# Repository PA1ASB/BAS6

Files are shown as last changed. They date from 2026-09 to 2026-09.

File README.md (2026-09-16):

# BAS6 - Remote controlled receive antenna switch for 6 beverage antennas

This project describes a 6-way receive antenna switch I built for a fellow radio amateur that allows to select one of six beverage wire antennas remotely and producing as little as possible noise around the connection to his receive amplifier. Using bi-stable relays makes it possible to completely disconnect power to the relays once an antenna has been selected. Switching is controlled by a small circuit, built in a tiny aluminium extrusion desktop enclosure, using two UP/DOWN tactile switches. Bi-colour LED’s on the from panel indicate the currently connected antenna and, when using the selection buttons, the next antenna to be switched on. Connection between the control station in the shack and the actual relay box requires 4 wires; using cheap UTP/FTP is therefore possible. The circuit should work over distances in excess of 200 meters as communication between the stations is done through two current loops (receive and transmit).

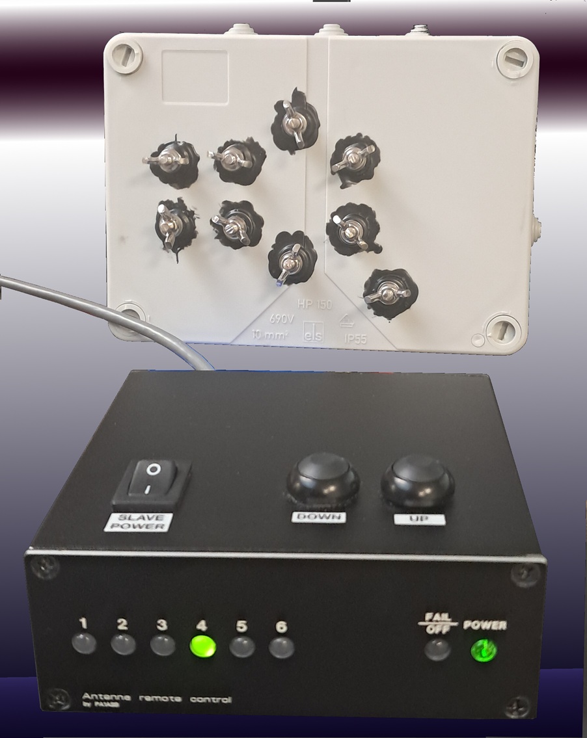
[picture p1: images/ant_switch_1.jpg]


Control unit and relay box communicate “digitally” by sending some pulses to and fro, the number of which determine what the relaybox should actually do. After executing a command, the circuit measures which relay is actually switched on / off and reports this back to the control unit again as a series of pulses. If for whatever reason the reported switch state differs from what has been commanded, an error is indicated so that  the user knows there’s something wrong. This will prevent unnecessary walks from the shack to the antenna connections: what is  indicated on the control unit is the actual state.

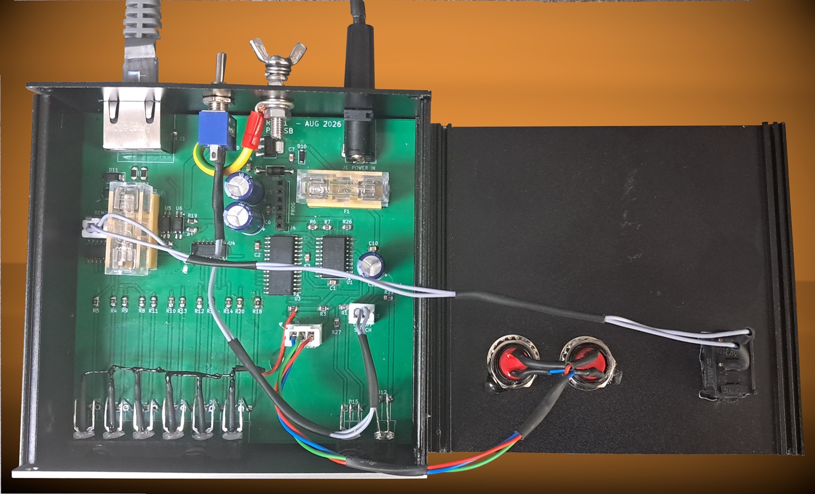
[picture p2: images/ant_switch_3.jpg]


The antennas are connected to the switch on the PVC junction box. I have made quite some effort in making the box and connections that are located outside of the box as watertight as possible but I guess that it is still advisable to make some additional protection to prevent direct exposure to the environment.

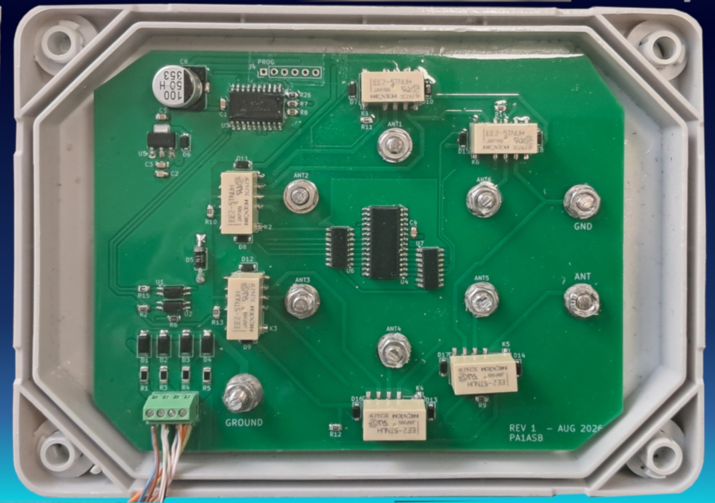
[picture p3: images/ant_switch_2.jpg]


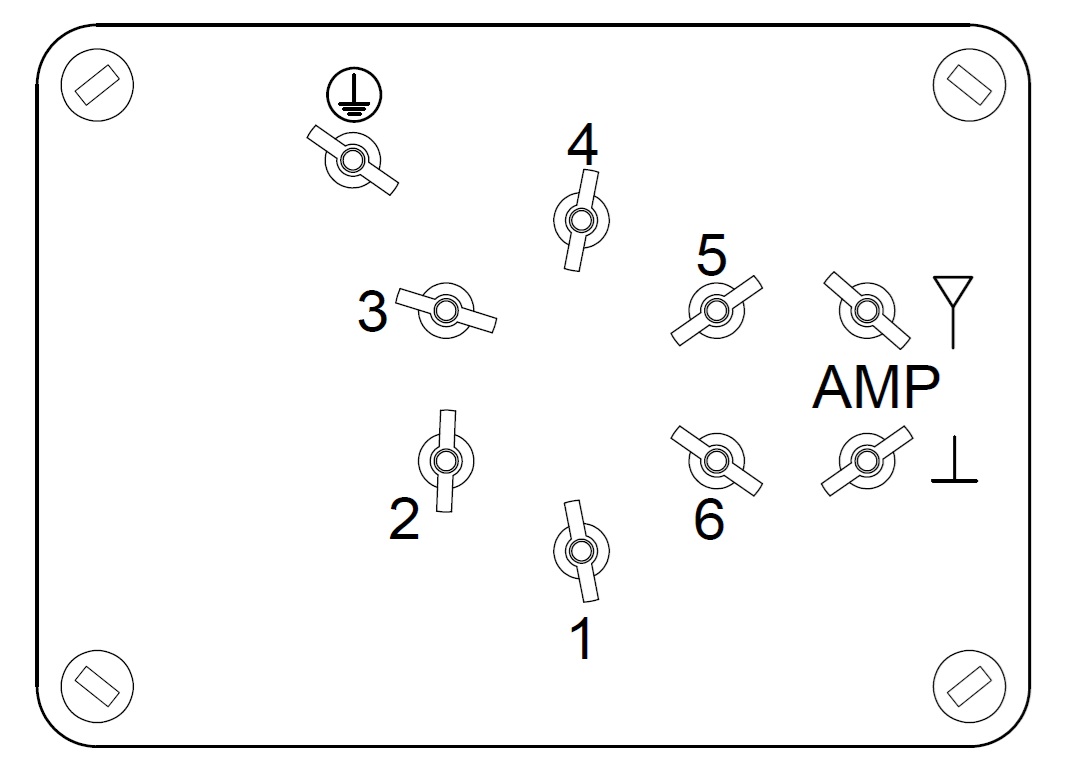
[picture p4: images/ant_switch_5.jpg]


You can find the schematics of both units both as PDF and KiCAD v10 files as well as the C sources. I have also included BOM files for the PCB’s. There’s some additional hardware required such as stainless steel hardware for the antenna connections and switches to control the relays; these are not mentioned in these files. I have built the software in MPLAB IDE with the XC8 1.33 compiler. The C source should also compile in the newer MPLAB X IDE with the newer compiler versions but I believe that there are some minor syntax changes between the old and new versions which obviously need to be resolved. Google will be your friend for that, I guess.

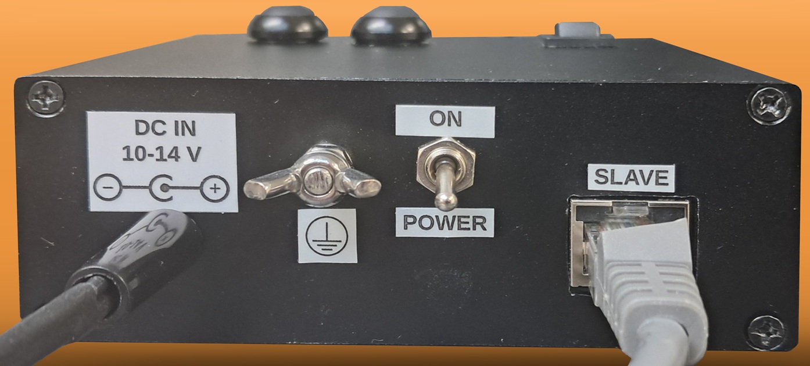
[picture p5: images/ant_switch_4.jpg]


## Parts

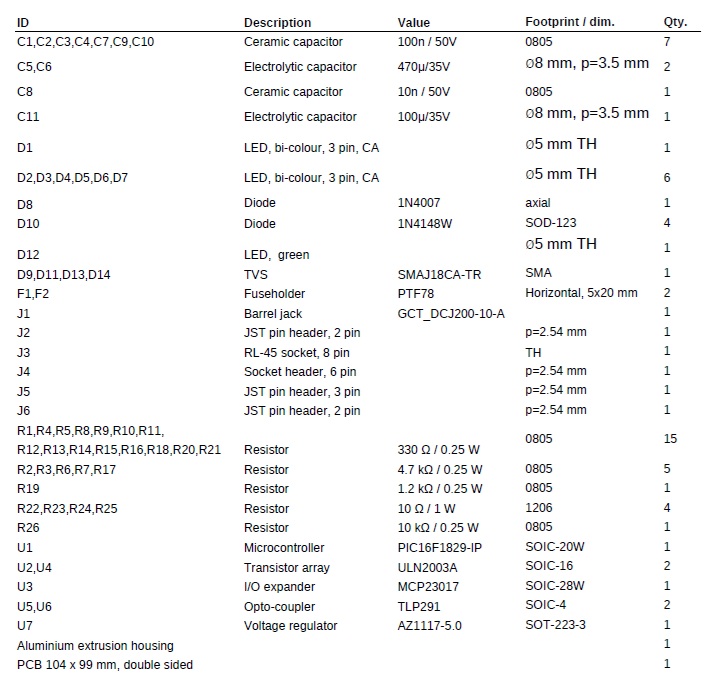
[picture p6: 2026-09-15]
hardware/controller/BOM.jpg

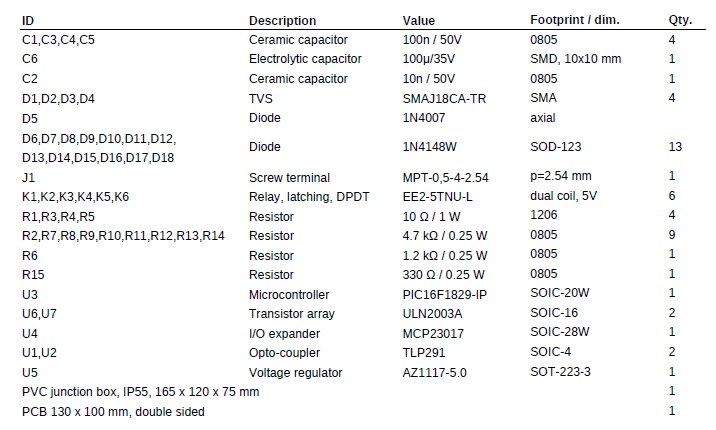
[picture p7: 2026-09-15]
hardware/switch/BOM.jpg

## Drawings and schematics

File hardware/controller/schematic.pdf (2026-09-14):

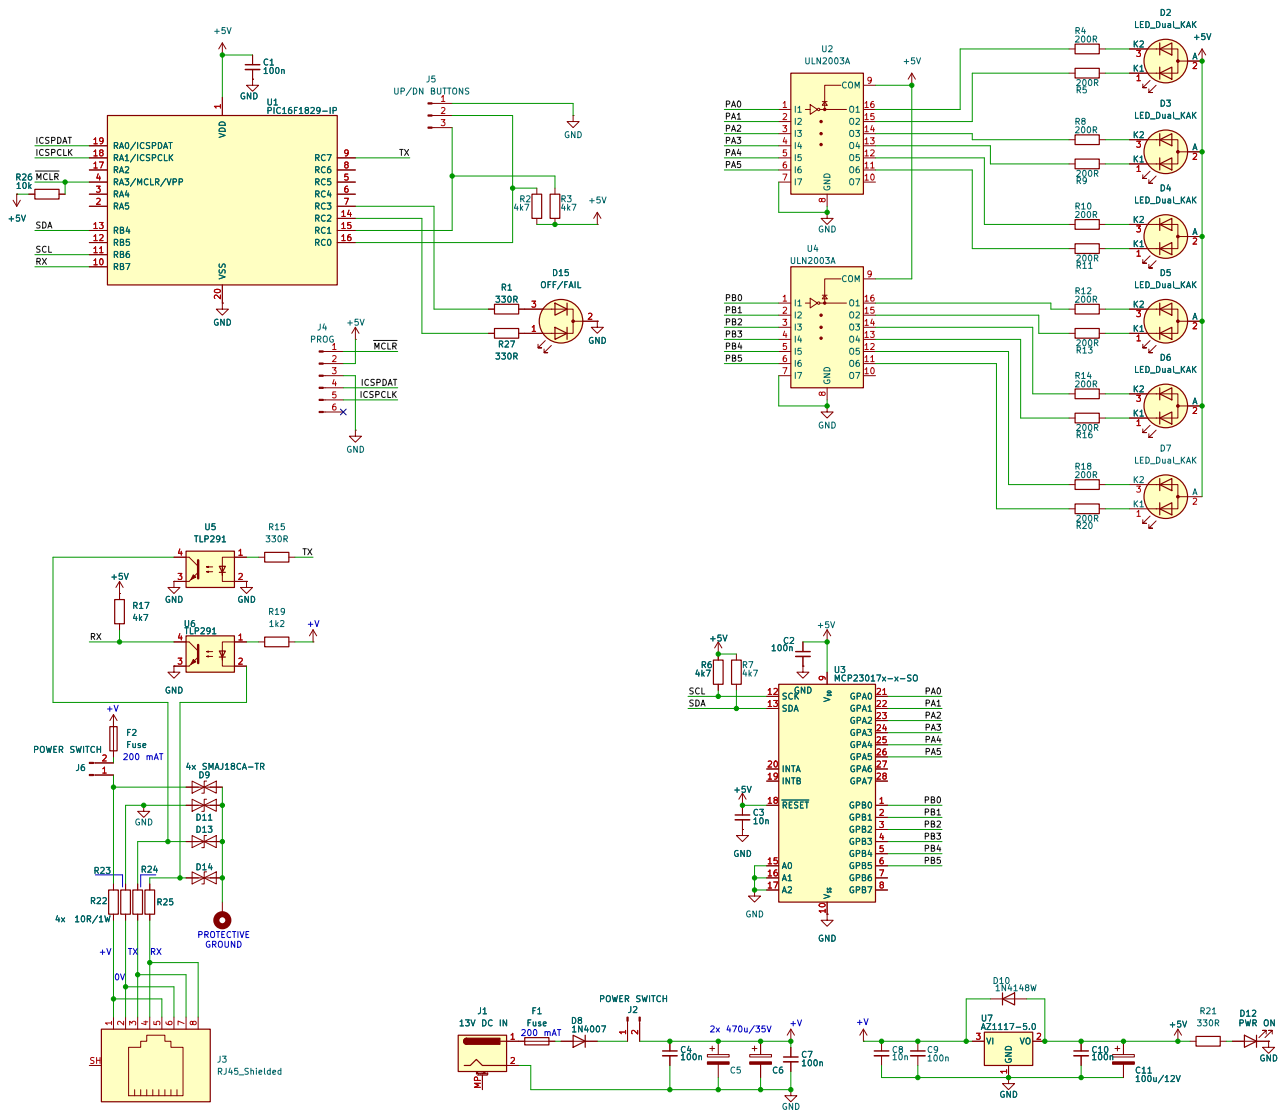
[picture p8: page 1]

1 RA5 2 RA4 3 RA3/MCLR/VPP 4 RC5 5 RC4 6 RC3 7 RC6 8 RC7 9 RB7 10 RB6 11 RB5 12 RB4 13 RC2 14 RC1 15 RC0 16 RA2 17 RA1/ICSPCLK 18 RA0/ICSPDAT 19 VSS 20 U1PIC16F1829-IP

1 RA5 2 RA4 3 RA3/MCLR/VPP 4 RC5 5 RC4 6 RC3 7 RC6 8 RC7 9 RB7 10 RB6 11 RB5 12 RB4 13 RC2 14 RC1 15 RC0 16 RA2 17 RA1/ICSPCLK 18 RA0/ICSPDAT 19 VSS 20 GND +5VR26

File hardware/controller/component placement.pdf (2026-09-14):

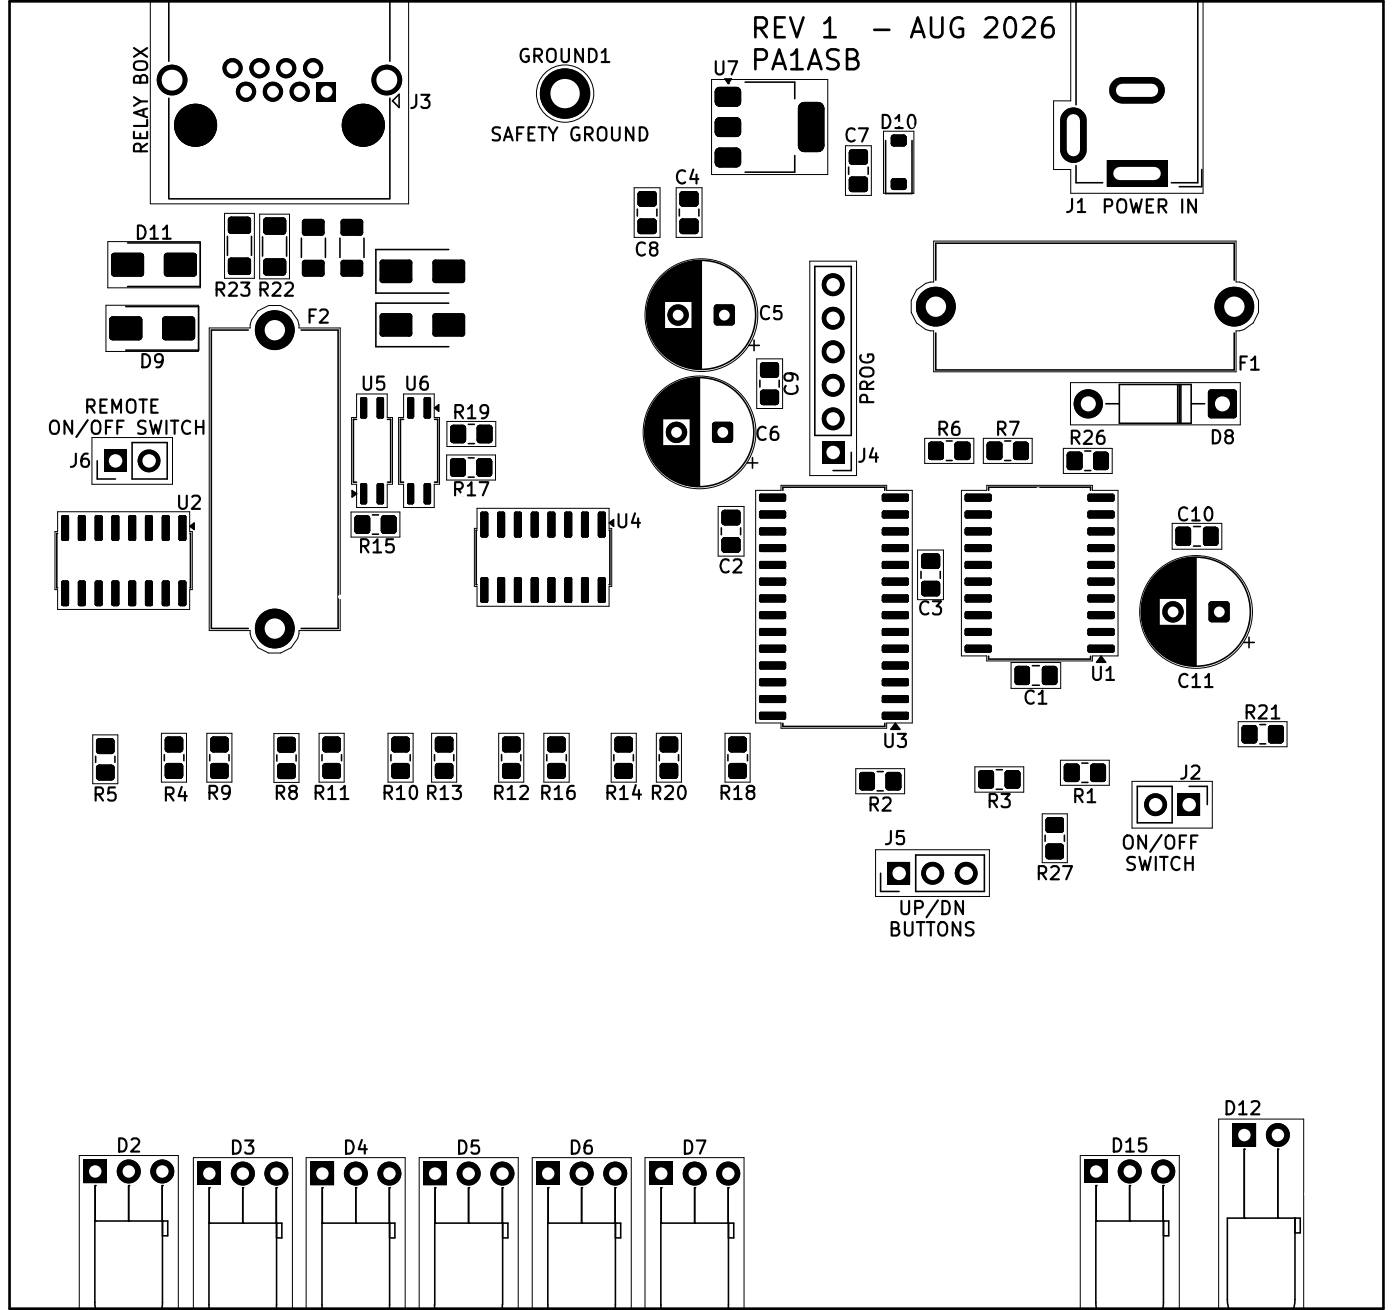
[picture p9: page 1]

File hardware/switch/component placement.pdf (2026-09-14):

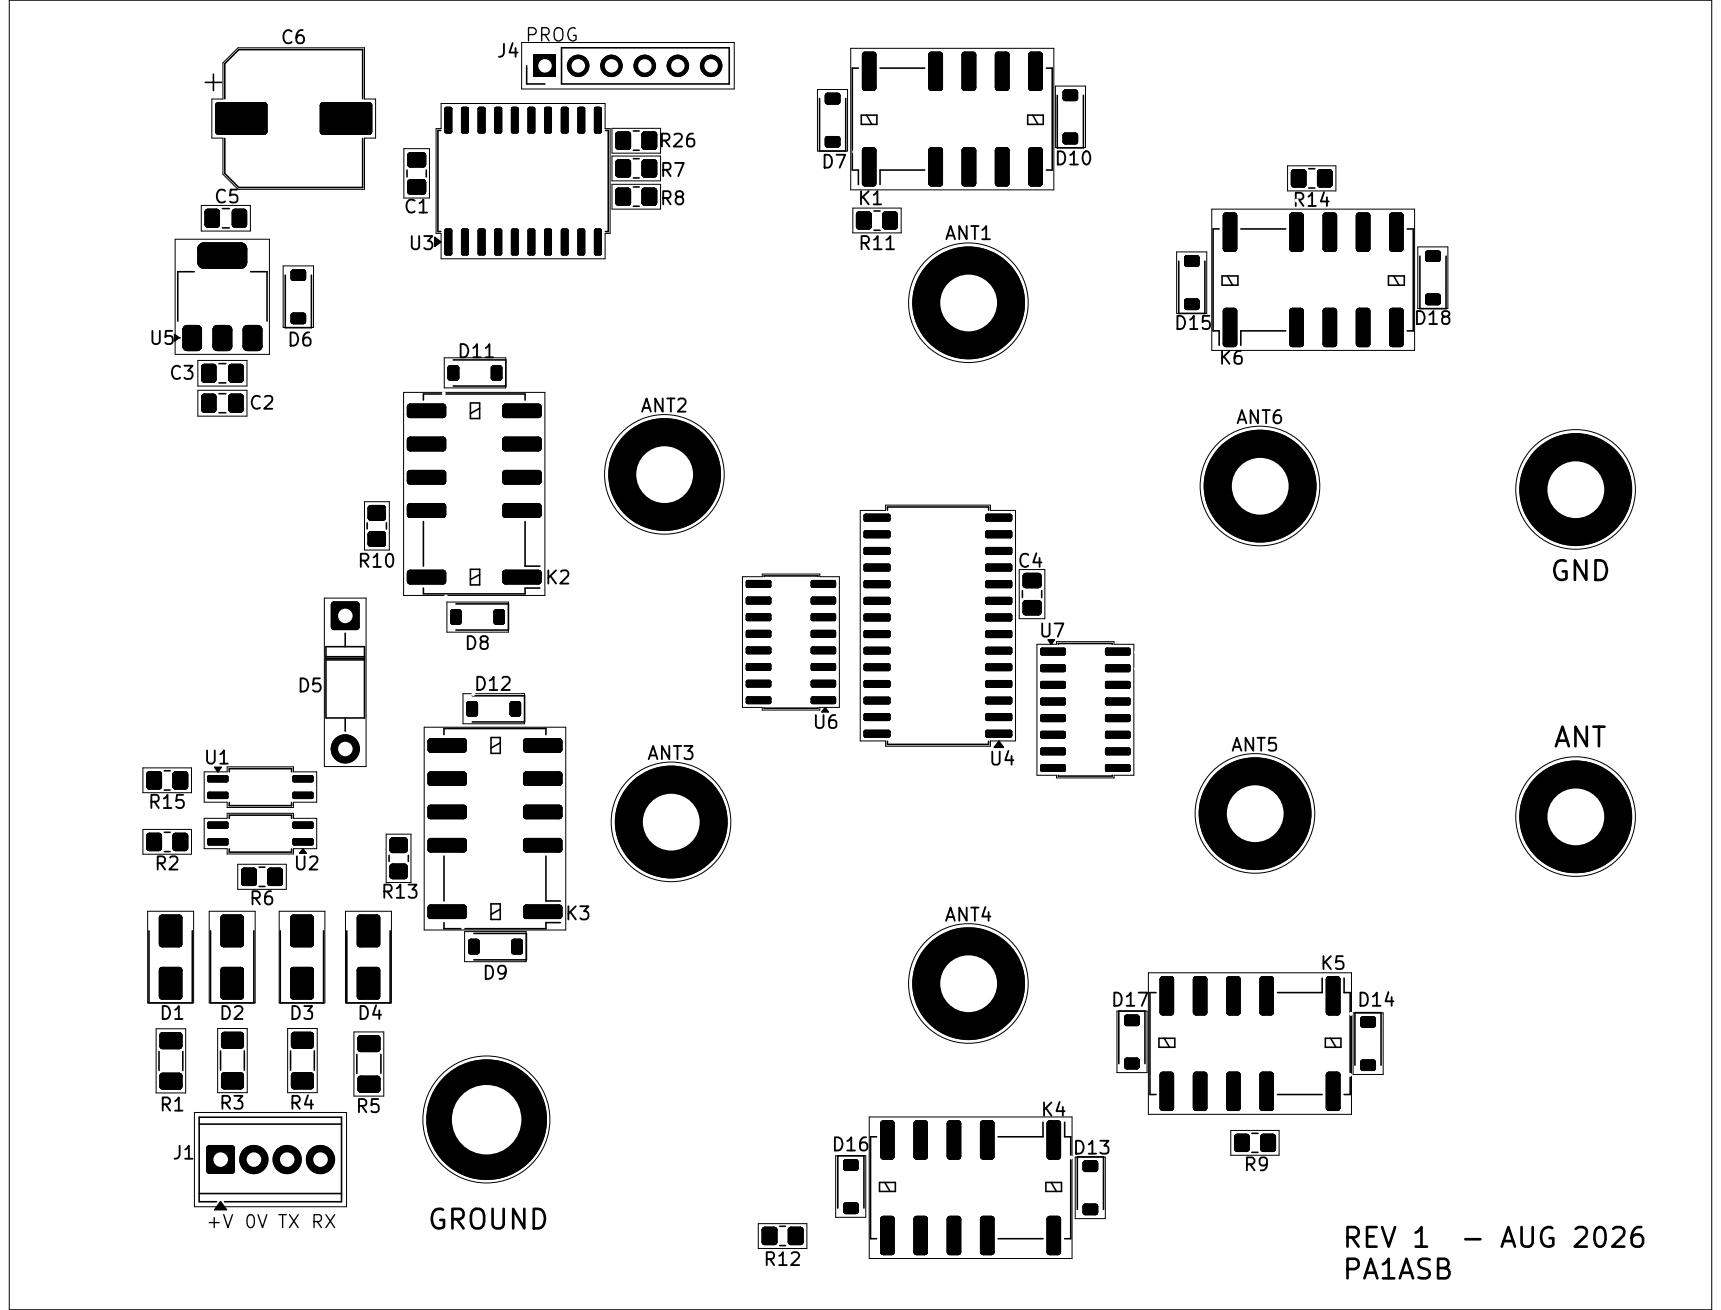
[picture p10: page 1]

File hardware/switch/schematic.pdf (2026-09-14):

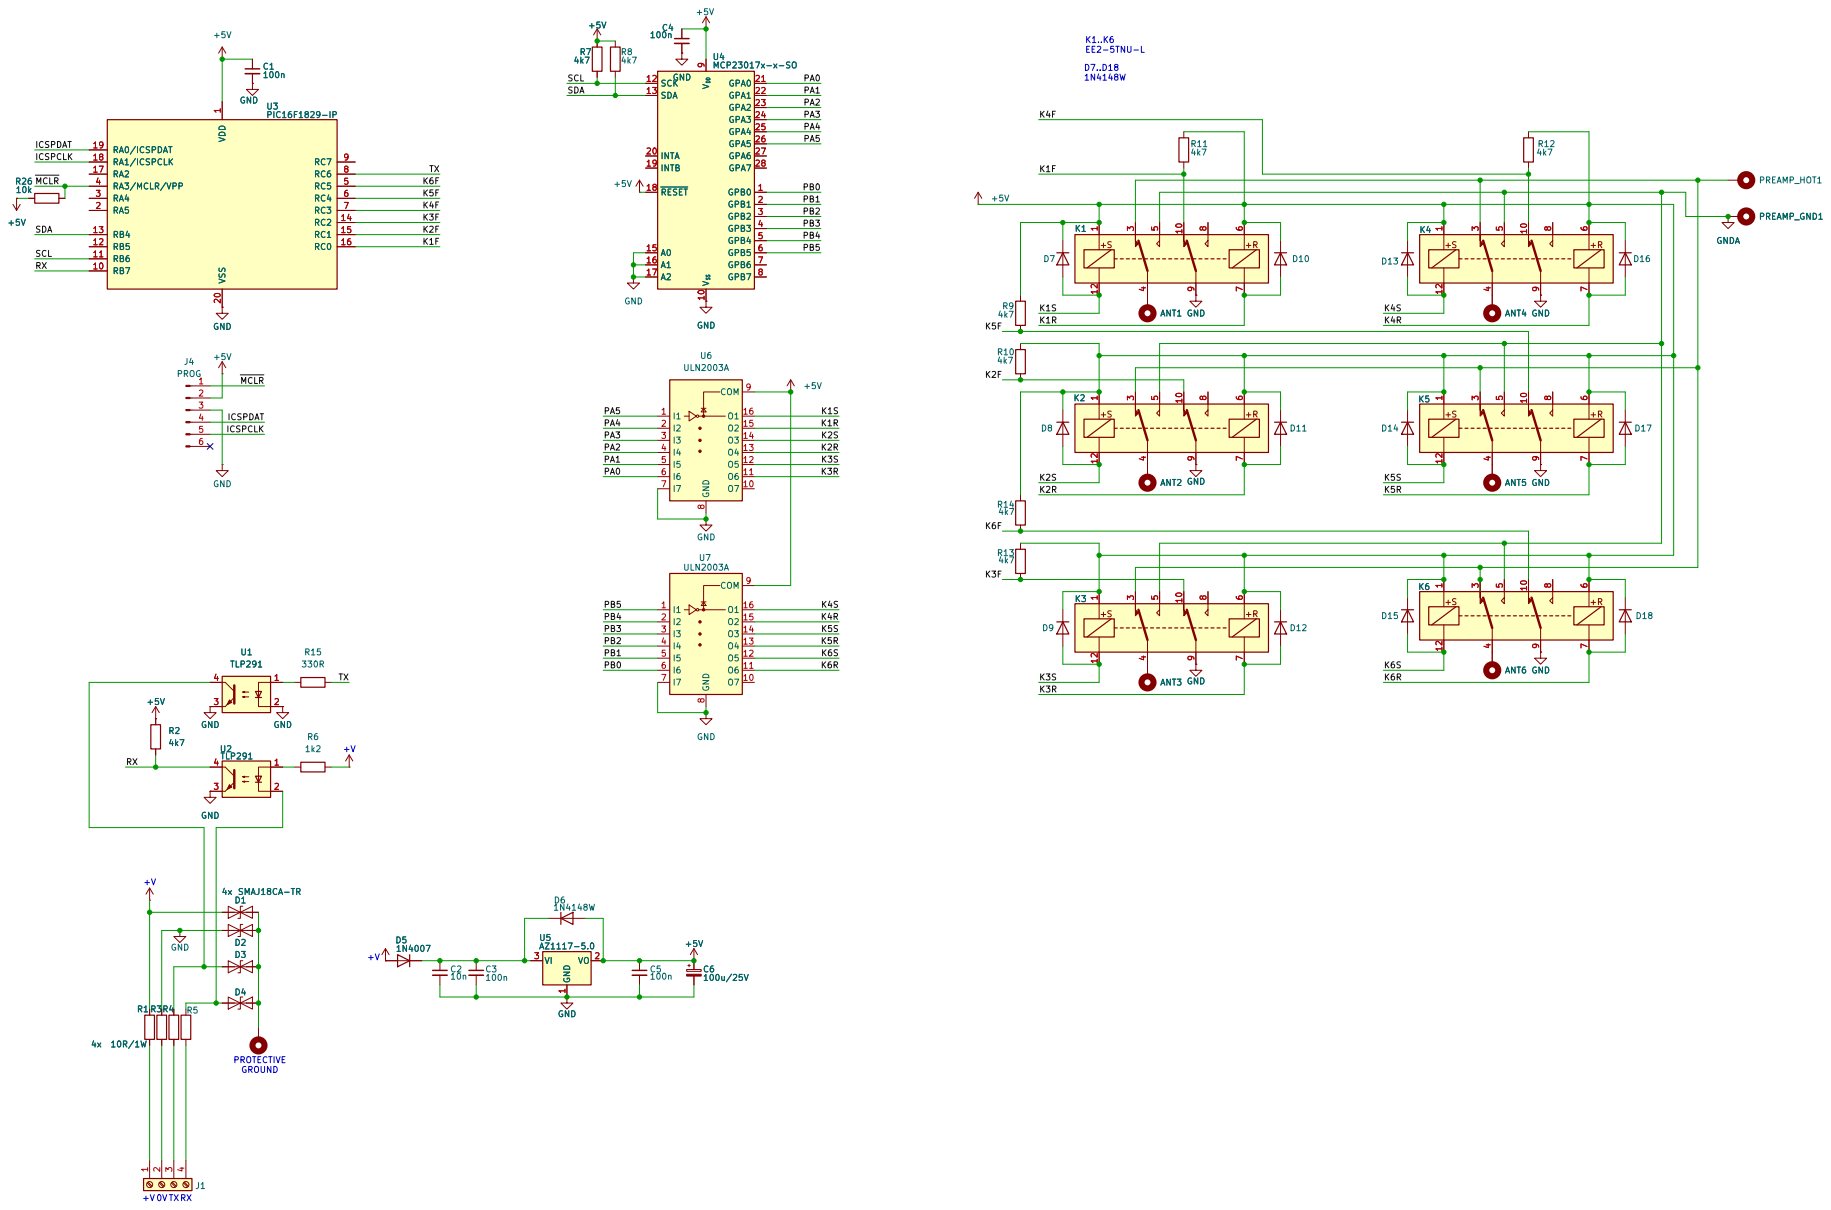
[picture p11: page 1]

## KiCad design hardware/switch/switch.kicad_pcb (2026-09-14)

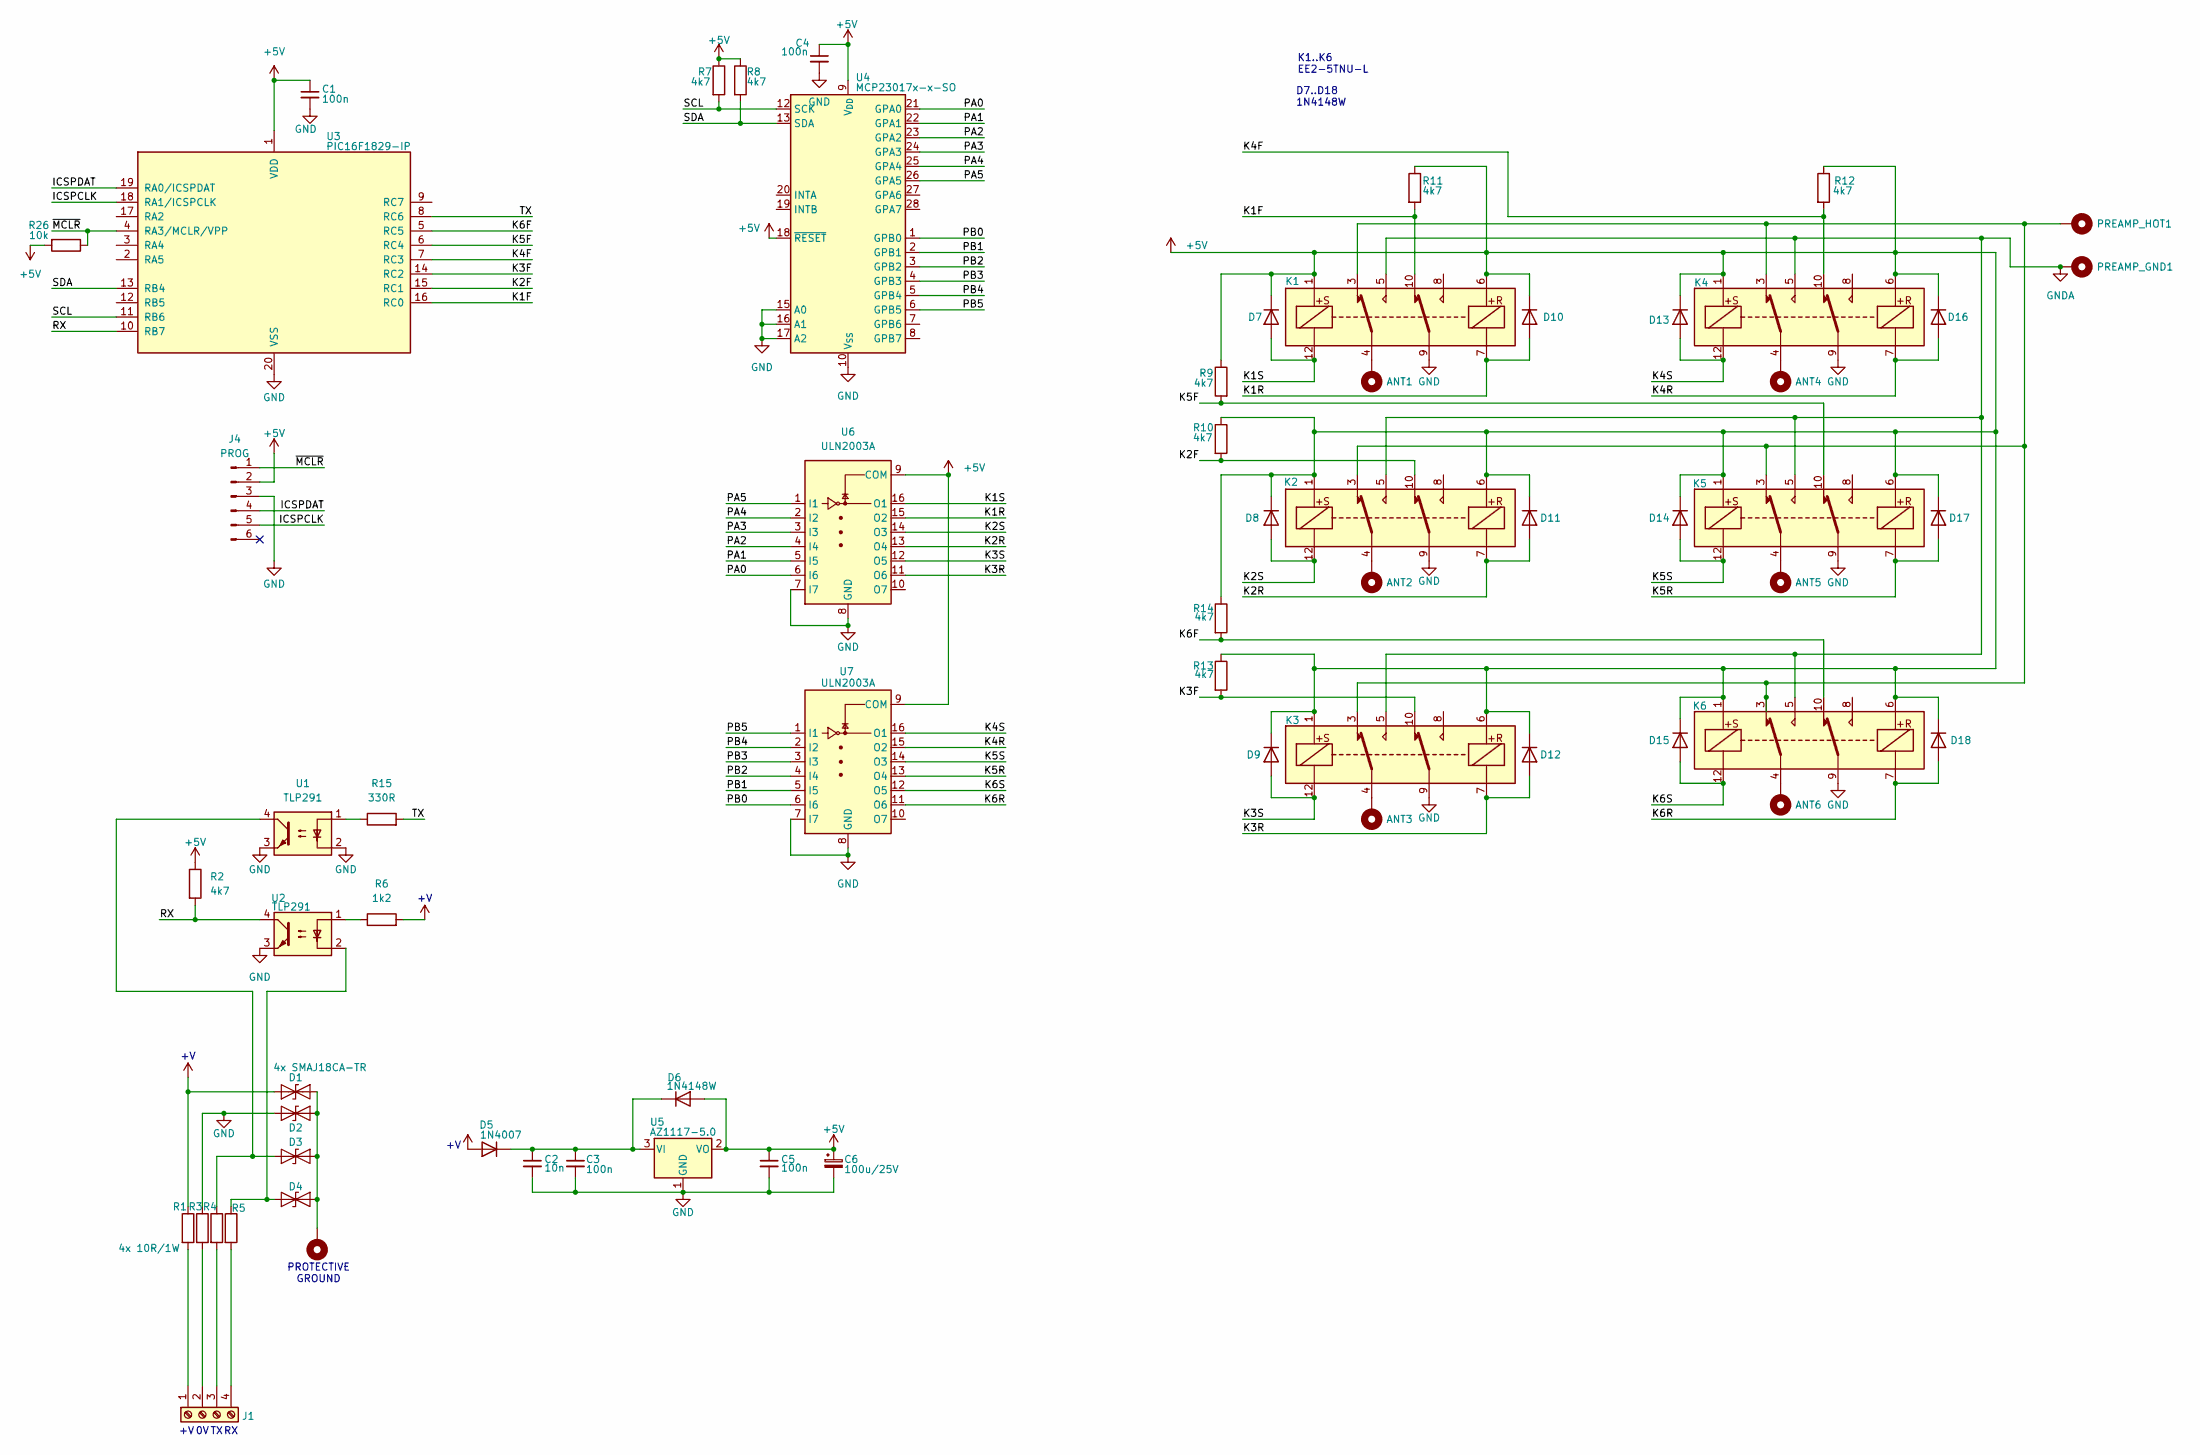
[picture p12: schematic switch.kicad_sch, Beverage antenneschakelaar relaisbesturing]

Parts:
ANT1, ANT2, ANT3, ANT4, ANT5, ANT6: MountingHole_Pad; MountingHole_4.3mm_M4_Pad_TopBottom
C1, C3, C4, C5: 100n; C_0805_2012Metric_Pad1.18x1.45mm_HandSolder
C2: 10n; C_0805_2012Metric_Pad1.18x1.45mm_HandSolder
C6: 100u/25V; CP_Elec_10x10
D1, D2, D3: SMAJ18CA-TR; D_SMA
D4: 4x SMAJ18CA-TR; D_SMA
D5: 1N4007; D_DO-41_SOD81_P10.16mm_Horizontal
D6, D7, D8, D9, D10, D11, D12, D13, D14, D15, D16, D17, D18: 1N4148W; D_SOD-123
GROUND1: MountingHole_Pad; MountingHole_5.3mm_M5_DIN965_Pad_TopBottom
J1: Screw_Terminal_01x04; TerminalBlock_Phoenix_MPT-0,5-4-2.54_1x04_P2.54mm_Horizontal
J4: PROG; PinHeader_1x06_P2.54mm_Vertical
K1, K2, K3, K4, K5, K6: EE2-5TNU-L; Relay_DPDT_Kemet_EE2_NU_DoubleCoil
PREAMP_GND1: MountingHole_Pad; MountingHole_4.3mm_M4_Pad_TopBottom
PREAMP_HOT1: MountingHole_Pad; MountingHole_4.3mm_M4_Pad_TopBottom
R1, R4, R5: 10R/1W; R_1206_3216Metric_Pad1.30x1.75mm_HandSolder
R2, R7, R8, R9, R10, R11, R12, R13, R14: 4k7; R_0805_2012Metric_Pad1.20x1.40mm_HandSolder
R3: 4x 10R/1W; R_1206_3216Metric_Pad1.30x1.75mm_HandSolder
R6: 1k2; R_0805_2012Metric_Pad1.20x1.40mm_HandSolder
R15: 330R; R_0805_2012Metric_Pad1.20x1.40mm_HandSolder
R26: 10k; R_0805_2012Metric_Pad1.20x1.40mm_HandSolder
U1, U2: TLP291; SOIC-4_4.55x2.6mm_P1.27mm
U3: PIC16F1829-IP; SOIC-20W_7.5x12.8mm_P1.27mm
U4: MCP23017x-x-SO; SOIC-28W_7.5x17.9mm_P1.27mm
U5: AZ1117-5.0; SOT-223-3_TabPin2
U6, U7: ULN2003A; SOIC-16_3.9x9.9mm_P1.27mm

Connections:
+5V: C1.1, C4.1, C5.1, C6.1, D6.2 (A), D7.1 (K), D8.1 (K), D9.1 (K), D10.1 (K), D11.1 (K), D12.1 (K), D13.1 (K), D14.1 (K), D15.1 (K), D16.1 (K), D17.1 (K), D18.1 (K), J4.2, K1.1, K1.6, K2.1, K2.6, K3.1, K3.6, K4.1, K4.6, K5.1, K5.6, K6.1, K6.6, R2.1, R7.1, R8.1, R9.1, R10.1, R11.1, R12.1, R13.1, R14.1, R26.2, U3.1 (VDD), U4.9 (V_{DD}), U4.18 (~RESET), U5.2 (VO), U6.9 (COM), U7.9 (COM)
+12V: D1.1 (A1), D5.2 (A), R1.1, R6.2
/ICSPCLK: J4.5, U3.18 (RA1/ICSPCLK)
/ICSPDAT: J4.4, U3.19 (RA0/ICSPDAT)
/K1F: K1.10, R11.2, U3.16 (RC0)
/K1R: D10.2 (A), K1.7, U6.15 (O2)
/K1S: D7.2 (A), K1.12, U6.16 (O1)
/K2F: K2.10, R10.2, U3.15 (RC1)
/K2R: D11.2 (A), K2.7, U6.13 (O4)
/K2S: D8.2 (A), K2.12, U6.14 (O3)
/K3F: K3.10, R13.2, U3.14 (RC2)
/K3R: D12.2 (A), K3.7, U6.11 (O6)
/K3S: D9.2 (A), K3.12, U6.12 (O5)
/K4F: K4.10, R12.2, U3.7 (RC3)
/K4R: D16.2 (A), K4.7, U7.15 (O2)
/K4S: D13.2 (A), K4.12, U7.16 (O1)
/K5F: K5.10, R9.2, U3.6 (RC4)
/K5R: D17.2 (A), K5.7, U7.13 (O4)
/K5S: D14.2 (A), K5.12, U7.14 (O3)
/K6F: K6.10, R14.2, U3.5 (RC5)
/K6R: D18.2 (A), K6.7, U7.11 (O6)
/K6S: D15.2 (A), K6.12, U7.12 (O5)
/PA0: U4.21 (GPA0), U6.6 (I6)
/PA1: U4.22 (GPA1), U6.5 (I5)
/PA2: U4.23 (GPA2), U6.4 (I4)
/PA3: U4.24 (GPA3), U6.3 (I3)
/PA4: U4.25 (GPA4), U6.2 (I2)
/PA5: U4.26 (GPA5), U6.1 (I1)
/PB0: U4.1 (GPB0), U7.6 (I6)
/PB1: U4.2 (GPB1), U7.5 (I5)
/PB2: U4.3 (GPB2), U7.4 (I4)
/PB3: U4.4 (GPB3), U7.3 (I3)
/PB4: U4.5 (GPB4), U7.2 (I2)
/PB5: U4.6 (GPB5), U7.1 (I1)
/RX: R2.2, U2.4, U3.10 (RB7)
/SCL: R7.2, U3.11 (RB6), U4.12 (SCK)
/SDA: R8.2, U3.13 (RB4), U4.13 (SDA)
/TX: R15.2, U3.8 (RC6)
/~MCLR: J4.1, R26.1, U3.4 (RA3/MCLR/VPP)
GND: C1.2, C2.2, C3.2, C4.2, C5.2, C6.2, D2.1 (A1), J4.3, K1.9, K2.9, K3.9, K4.9, K5.9, K6.9, R3.1, U1.2, U1.3, U2.3, U3.20 (VSS), U4.10 (V_{SS}), U4.15 (A0), U4.16 (A1), U4.17 (A2), U5.1 (GND), U6.7 (I7), U6.8 (GND), U7.7 (I7), U7.8 (GND)
GNDA: K1.5, K2.5, K3.5, K4.5, K5.5, K6.5, PREAMP_GND1.1 (1_1)
unnamed: ANT1.1 (1_1), K1.4
unnamed: ANT2.1 (1_1), K2.4
unnamed: ANT3.1 (1_1), K3.4
unnamed: ANT4.1 (1_1), K4.4
unnamed: ANT5.1 (1_1), K5.4
unnamed: ANT6.1 (1_1), K6.4
unnamed: D1.2 (A2), D2.2 (A2), D3.2 (A2), D4.2 (A2), GROUND1.1 (1_1)
unnamed: D3.1 (A1), R4.1, U1.4
unnamed: D4.1 (A1), R5.1, U2.2
unnamed: C2.1, C3.1, D5.1 (K), D6.1 (K), U5.3 (VI)
unnamed: J1.1, R1.2
unnamed: J1.2, R3.2
unnamed: J1.3, R4.2
unnamed: J1.4, R5.2
unnamed: K1.3, K2.3, K3.3, K4.3, K5.3, K6.3, PREAMP_HOT1.1 (1_1)
unnamed: R6.1, U2.1
unnamed: R15.1, U1.1

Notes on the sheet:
K1..K6 EE2-5TNU-L
D7..D18 1N4148W
PROTECTIVE GROUND

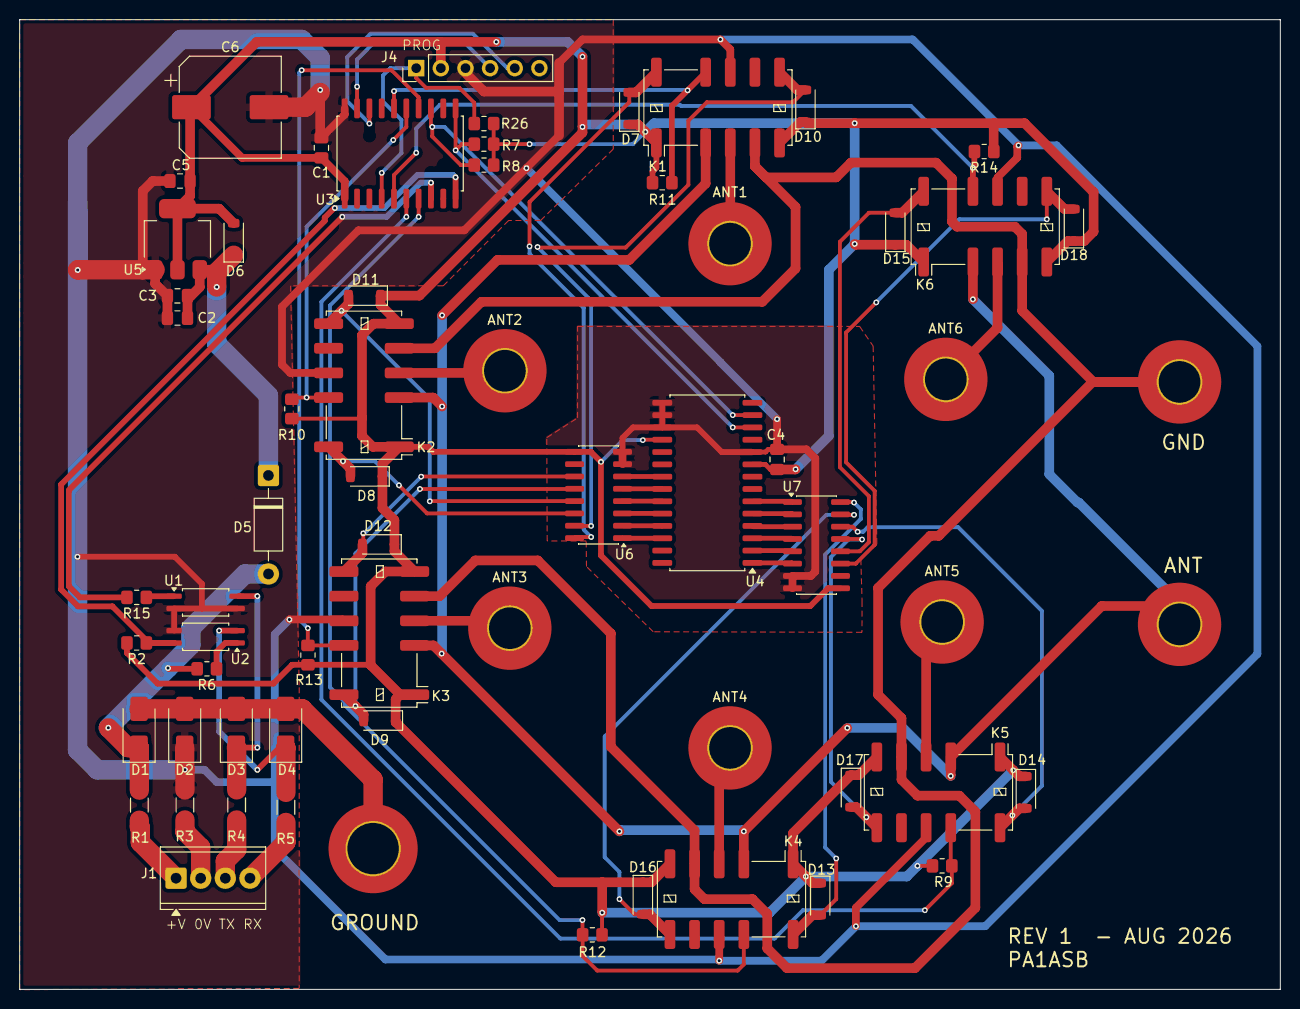
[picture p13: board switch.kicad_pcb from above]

Board: 2 copper layers, 130.0 x 100.0 mm, 64 parts (0 on the bottom side), 58 nets.

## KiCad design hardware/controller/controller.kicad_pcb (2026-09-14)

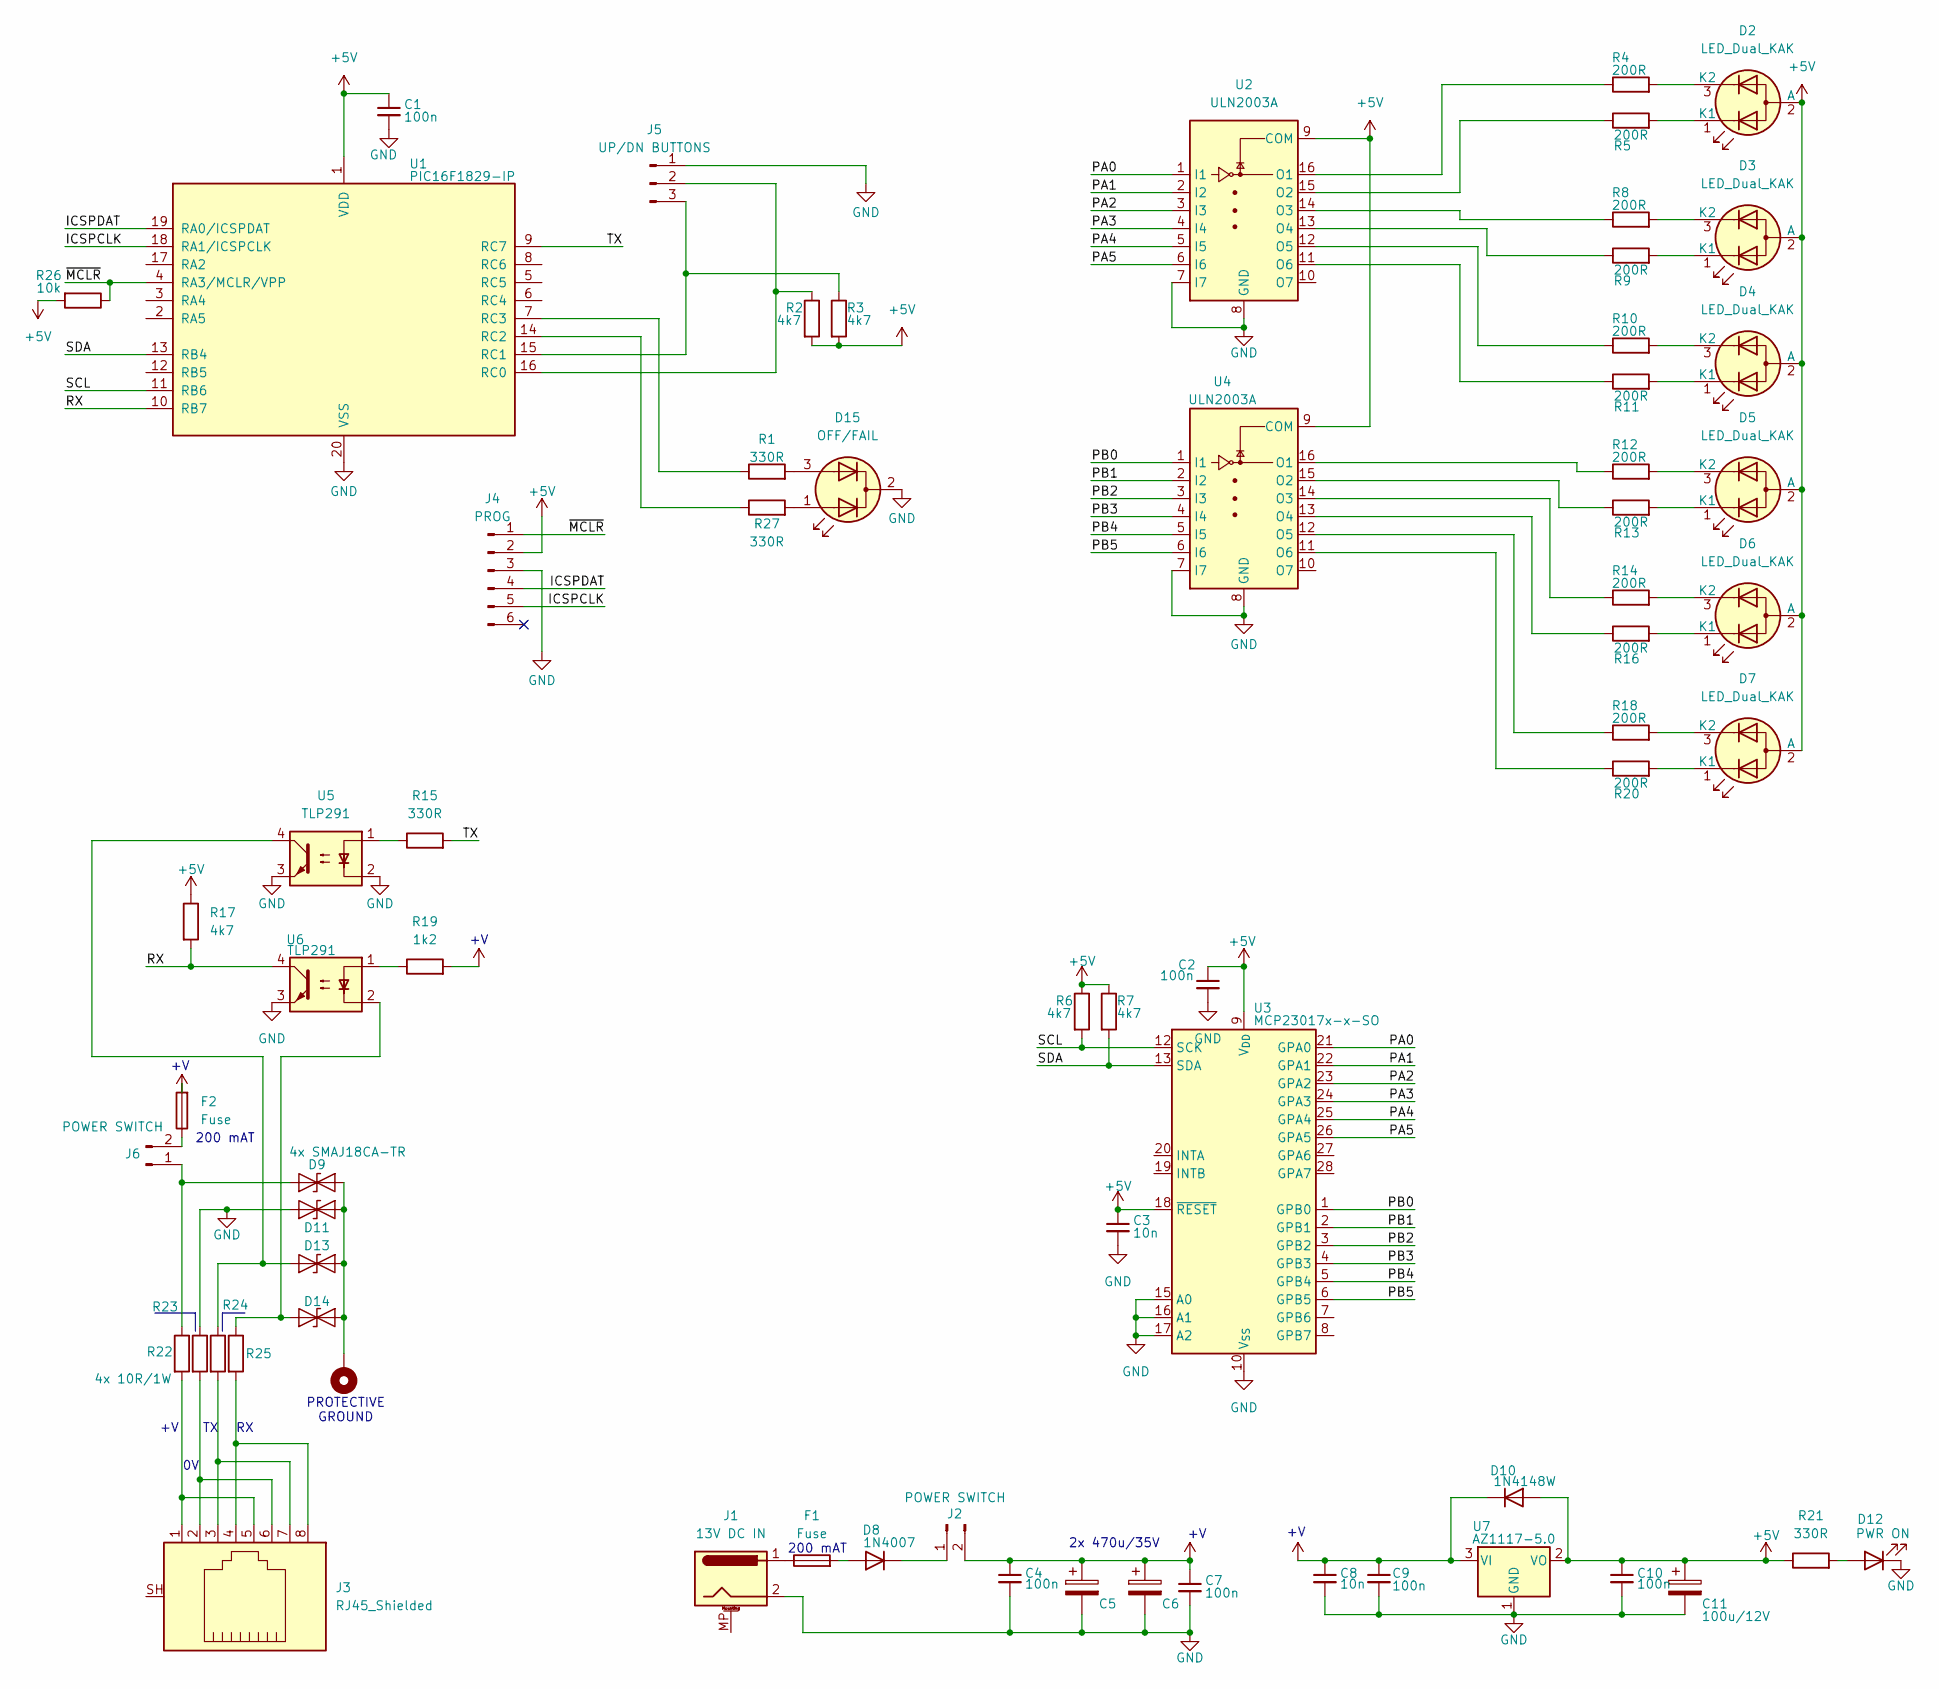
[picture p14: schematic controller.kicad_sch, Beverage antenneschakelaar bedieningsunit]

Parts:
C1, C2, C4, C7, C9, C10: 100n; C_0805_2012Metric_Pad1.18x1.45mm_HandSolder
C3, C8: 10n; C_0805_2012Metric_Pad1.18x1.45mm_HandSolder
C5, C6: 470u/35V; CP_Radial_D8.0mm_P3.50mm
C11: 100u/12V; CP_Radial_D8.0mm_P3.50mm
D2, D3, D4, D5, D6, D7: LED_Dual_KAK; LED_D5.0mm-3_Horizontal_O3.81mm_Z3.0mm
D8: 1N4007; D_DO-41_SOD81_P10.16mm_Horizontal
D9, D11, D13: SMAJ18CA-TR; D_SMA
D10: 1N4148W; D_SOD-123
D12: PWR ON; LED_D5.0mm_Horizontal_O6.35mm_Z15.0mm
D14: 4x SMAJ18CA-TR; D_SMA
D15: OFF/FAIL; LED_D5.0mm-3_Horizontal_O3.81mm_Z3.0mm
F1, F2: Fuse; Fuseholder_Cylinder-5x20mm_Stelvio-Kontek_PTF78_Horizontal_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
GROUND1: MountingHole_Pad; MountingHole_2.2mm_M2_DIN965_Pad_TopBottom
J1: 13V DC IN; BarrelJack_GCT_DCJ200-10-A_Horizontal
J2, J6: POWER SWITCH; PinHeader_1x02_P2.54mm_Vertical
J3: RJ45_Shielded; RJ45_Amphenol_RJHSE5380
J4: PROG; PinHeader_1x06_P2.54mm_Vertical
J5: UP/DN BUTTONS; PinHeader_1x03_P2.54mm_Vertical
R1, R15, R21, R27: 330R; R_0805_2012Metric_Pad1.20x1.40mm_HandSolder
R2, R3, R6, R7, R17: 4k7; R_0805_2012Metric_Pad1.20x1.40mm_HandSolder
R4, R5, R8, R9, R10, R11, R12, R13, R14, R16, R18, R20: 200R; R_0805_2012Metric_Pad1.20x1.40mm_HandSolder
R19: 1k2; R_0805_2012Metric_Pad1.20x1.40mm_HandSolder
R22, R24, R25: 10R/1W; R_1206_3216Metric_Pad1.30x1.75mm_HandSolder
R23: 4x 10R/1W; R_1206_3216Metric_Pad1.30x1.75mm_HandSolder
R26: 10k; R_0805_2012Metric_Pad1.20x1.40mm_HandSolder
U1: PIC16F1829-IP; SOIC-20W_7.5x12.8mm_P1.27mm
U2, U4: ULN2003A; SOIC-16_3.9x9.9mm_P1.27mm
U3: MCP23017x-x-SO; SOIC-28W_7.5x17.9mm_P1.27mm
U5, U6: TLP291; SOIC-4_4.55x2.6mm_P1.27mm
U7: AZ1117-5.0; SOT-223-3_TabPin2

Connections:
+5V: C1.1, C2.1, C3.1, C10.1, C11.1, D2.2 (A), D3.2 (A), D4.2 (A), D5.2 (A), D6.2 (A), D7.2 (A), D10.2 (A), J4.2, R2.2, R3.2, R6.1, R7.1, R17.1, R21.1, R26.2, U1.1 (VDD), U2.9 (COM), U3.9 (V_{DD}), U3.18 (~RESET), U4.9 (COM), U7.2 (VO)
+12V: C4.1, C5.1, C6.1, C7.1, C8.1, C9.1, D10.1 (K), F2.2, J2.2, R19.2, U7.3 (VI)
/ICSPCLK: J4.5, U1.18 (RA1/ICSPCLK)
/ICSPDAT: J4.4, U1.19 (RA0/ICSPDAT)
/PA0: U2.1 (I1), U3.21 (GPA0)
/PA1: U2.2 (I2), U3.22 (GPA1)
/PA2: U2.3 (I3), U3.23 (GPA2)
/PA3: U2.4 (I4), U3.24 (GPA3)
/PA4: U2.5 (I5), U3.25 (GPA4)
/PA5: U2.6 (I6), U3.26 (GPA5)
/PB0: U3.1 (GPB0), U4.1 (I1)
/PB1: U3.2 (GPB1), U4.2 (I2)
/PB2: U3.3 (GPB2), U4.3 (I3)
/PB3: U3.4 (GPB3), U4.4 (I4)
/PB4: U3.5 (GPB4), U4.5 (I5)
/PB5: U3.6 (GPB5), U4.6 (I6)
/RX: R17.2, U1.10 (RB7), U6.4
/SCL: R6.2, U1.11 (RB6), U3.12 (SCK)
/SDA: R7.2, U1.13 (RB4), U3.13 (SDA)
/TX: R15.2, U1.9 (RC7)
/~MCLR: J4.1, R26.1, U1.4 (RA3/MCLR/VPP)
GND: C1.2, C2.2, C3.2, C4.2, C5.2, C6.2, C7.2, C8.2, C9.2, C10.2, C11.2, D11.1 (A1), D12.1 (K), D15.2 (K), J1.2, J4.3, J5.1, R23.1, U1.20 (VSS), U2.7 (I7), U2.8 (GND), U3.10 (V_{SS}), U3.15 (A0), U3.16 (A1), U3.17 (A2), U4.7 (I7), U4.8 (GND), U5.2, U5.3, U6.3, U7.1 (GND)
unnamed: D2.1 (K1), R5.2
unnamed: D2.3 (K2), R4.2
unnamed: D3.1 (K1), R9.2
unnamed: D3.3 (K2), R8.2
unnamed: D4.1 (K1), R11.2
unnamed: D4.3 (K2), R10.2
unnamed: D5.1 (K1), R13.2
unnamed: D5.3 (K2), R12.2
unnamed: D6.1 (K1), R16.2
unnamed: D6.3 (K2), R14.2
unnamed: D7.1 (K1), R20.2
unnamed: D7.3 (K2), R18.2
unnamed: D8.2 (A), F1.2
unnamed: D8.1 (K), J2.1
unnamed: D9.1 (A1), J6.1, R22.1
unnamed: D9.2 (A2), D11.2 (A2), D13.2 (A2), D14.2 (A2), GROUND1.1 (1_1)
unnamed: D12.2 (A), R21.2
unnamed: D13.1 (A1), R24.1, U5.4
unnamed: D14.1 (A1), R25.1, U6.2
unnamed: D15.1 (A1), R27.2
unnamed: D15.3 (A2), R1.2
unnamed: F1.1, J1.1
unnamed: J3.1, J3.5, R22.2
unnamed: J3.2, J3.6, R23.2
unnamed: J3.3, J3.7, R24.2
unnamed: J3.4, J3.8, R25.2
unnamed: J5.2, R2.1, U1.16 (RC0)
unnamed: J5.3, R3.1, U1.15 (RC1)
unnamed: F2.1, J6.2
unnamed: R15.1, U5.1
unnamed: R19.1, U6.1
unnamed: R27.1, U1.14 (RC2)
unnamed: R1.1, U1.7 (RC3)
unnamed: R4.1, U2.16 (O1)
unnamed: R5.1, U2.15 (O2)
unnamed: R8.1, U2.14 (O3)
unnamed: R9.1, U2.13 (O4)
unnamed: R10.1, U2.12 (O5)
unnamed: R11.1, U2.11 (O6)
unnamed: R12.1, U4.16 (O1)
unnamed: R13.1, U4.15 (O2)
unnamed: R14.1, U4.14 (O3)
unnamed: R16.1, U4.13 (O4)
unnamed: R18.1, U4.12 (O5)
unnamed: R20.1, U4.11 (O6)

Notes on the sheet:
PROTECTIVE GROUND
2x 470u/35V
200 mAT

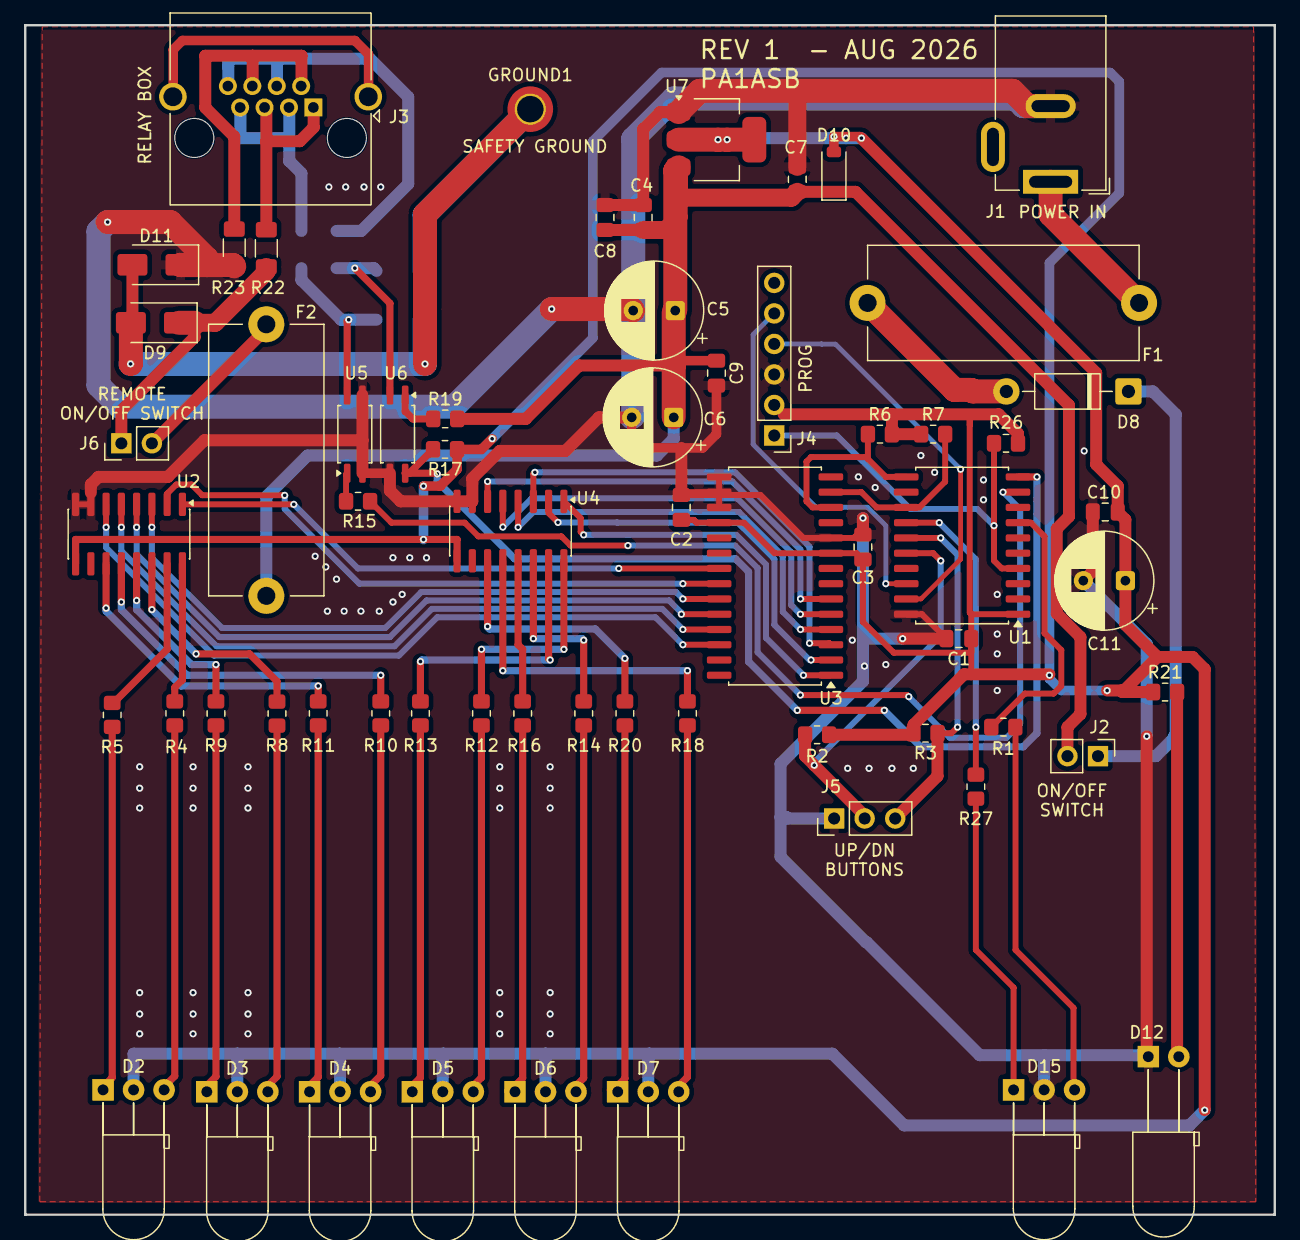
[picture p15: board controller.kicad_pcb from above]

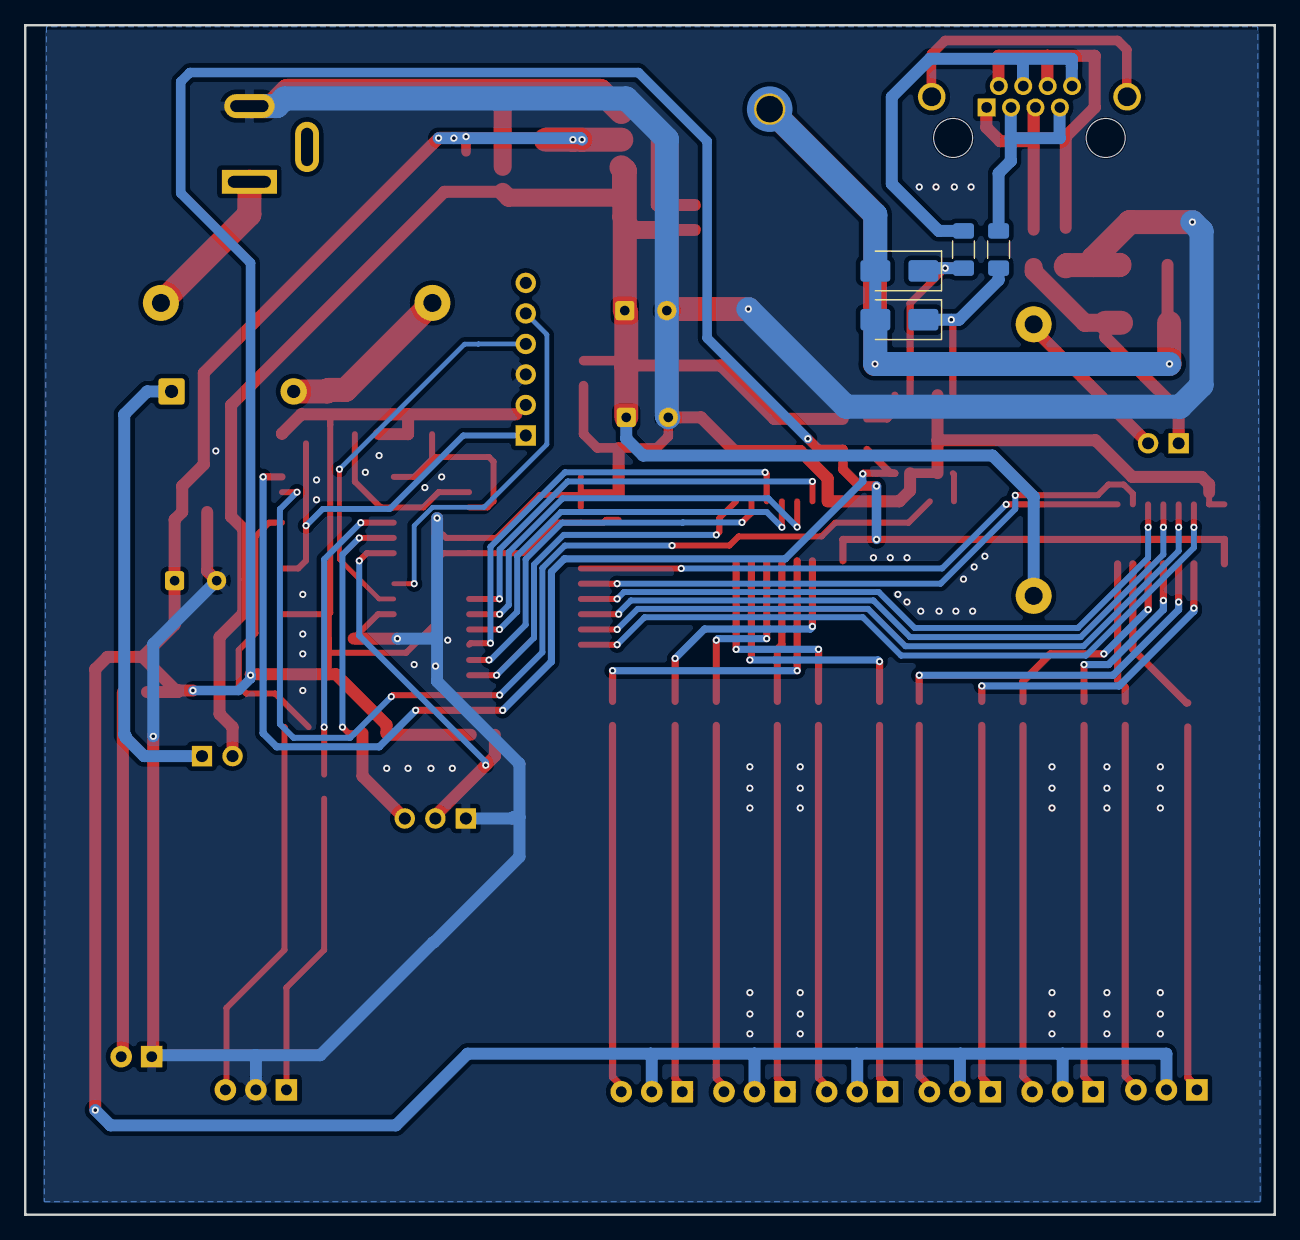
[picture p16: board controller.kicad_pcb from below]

Board: 2 copper layers, 104.0 x 99.0 mm, 68 parts (4 on the bottom side), 67 nets.

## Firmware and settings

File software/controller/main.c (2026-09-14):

/******************************************************************************/
/*                                                                            */
/* FILENAME     :	main.c                                                    */
/* DESCRIPTION  :   Control unit for driving a remote operated 6 relay switch */
/*                  through a 2-wire pulse modulated current loop.            */
/* WRITTEN BY   :   PA1ASB / M. van den Berg                                  */
/*                                                                            */
/* |--------------+-------+----------+---------------------------------------|*/
/* | DATE         | REV.  | BY       | CHANGES                               |*/
/* |--------------+-------+----------+---------------------------------------+*/
/* | AUG 30 2026  |     0 | MvdB     | INITIAL VERSION                       |*/
/* | SEP 13 2026  |     1 | MvdB     | FINAL RELEASE VERSION                 |*/
/* |              |       |          |                                       |*/
/* |--------------+-------+----------+---------------------------------------|*/
/*                                                                            */
/* ========================================================================== */
/*                                                                            */
/* MIT License                                                                */
/*                                                                            */
/* Copyright (c) 2026 - M. van den Berg / PA1ASB                              */
/*                                                                            */
/* Permission is hereby granted,  free of charge,  to any person  obtaining a */
/* copy of this software and associated documentation files (the "Software"), */
/* to deal in the Software without restriction, including without  limitation */
/* the rights to use, copy,  modify, merge,  publish,  distribute, sublicense,*/
/* and/or  sell copies of  the Software,  and to  permit persons  to whom the */ 
/* Software is furnished to do so, subject to the following conditions:       */
/*                                                                            */
/* The above copyright notice and this permission notice shall be included in */
/* all copies or substantial portions of the Software.                        */
/*                                                                            */
/* THE SOFTWARE IS PROVIDED "AS IS", WITHOUT WARRANTY OF ANY KIND, EXPRESS OR */
/* IMPLIED,  INCLUDING BUT  NOT LIMITED TO THE WARRANTIES OF MERCHANTABILITY, */
/* FITNESS  FOR A PARTICULAR  PURPOSE AND NONINFRINGEMENT.  IN NO EVENT SHALL */
/* THE AUTHORS OR COPYRIGHT HOLDERS BE LIABLE FOR ANY CLAIM, DAMAGES OR OTHER */
/* LIABILITY,  WHETHER IN AN ACTION OF CONTRACT,  TORT OR OTHERWISE,  ARISING */
/* FROM,  OUT OF OR IN  CONNECTION WITH  THE SOFTWARE  OR  THE  USE OR  OTHER */
/* DEALINGS IN THE SOFTWARE.                                                  */
/*                                                                            */
/******************************************************************************/
#include "main.h"

/******************************************************************************/
/* main()
** ------
*/
void main(void) 
{
	bool no_ant_req = true;			// First enquiry without request!
	uint16_t start_delay = 0;
    uint8_t rx_data = 0;	
	bool start_found = false;
    uint16_t timeout = 0;		
    System_Init();					// Initialize the hardware
    MCP23017_Init(MCP23017_ADDR);	// Initialize the I/O expander that drives the LED's
    TX_PIN = 0;						// Make sure the TX line is LOW
	currentState = STATE_START;		// Initial machine state
	Set_Status_LED(COLOR_RED);

// Wait 1 second to allow slave to start
	while (start_delay < 1000)
	{
		CLRWDT();
		start_delay++;
		__delay_ms(1);
	}

    while(1) 
	{
        CLRWDT();
        switch (currentState) 		
		{            
// -------------------------------------------------------------
// STATE: START (System start / request relay state)
// -------------------------------------------------------------
            case STATE_START:
                currentState = STATE_REQ_INFO;
				no_ant_req = true;
                break;
// -------------------------------------------------------------
// STATE: REQ_INFO (Get relay state from slave)
// -------------------------------------------------------------
			case STATE_REQ_INFO:
				if(Send_Frame(9))
	               	currentState = STATE_RECEIVE;
				else
				{
					currentState = STATE_ERROR;
					DisplayAntennaSelection(0, 0);
                	Set_Status_LED(COLOR_RED);
				}
			
				break;
// -------------------------------------------------------------
// STATE: IDLE (Wait for button press and 1 sec timeout)
// -------------------------------------------------------------
            case STATE_IDLE:
// UP button
                if (BTN_UP == 0) 
				{
                    __delay_ms(50); // debounce
                    if (BTN_UP == 0) 
					{
                        selected_antenna++;
                        if (selected_antenna > 7) 
							selected_antenna = 1;
                        timer_1sec_counter = 0;
                        timer_1sec_active = true;
                        timer_1sec_expired = false;
						DisplayAntennaSelection(current_antenna, selected_antenna);
                        while(BTN_UP == 0) 
							CLRWDT();
                    }
                }
// DOWN button  
                if (BTN_DN == 0) 
				{
                    __delay_ms(50);
                    if (BTN_DN == 0) 
					{
                        if (selected_antenna <= 1) 
							selected_antenna = 7;
                        else 
							selected_antenna--;
                        timer_1sec_counter = 0;
                        timer_1sec_active = true;
                        timer_1sec_expired = false;
						DisplayAntennaSelection(current_antenna, selected_antenna);
                        while(BTN_DN == 0) 
							CLRWDT();
                    }
                }
                
                if (timer_1sec_expired) 
				{
// UP/DOWN untouched for >1 sec
                    timer_1sec_expired = false;
                    if (selected_antenna != current_antenna) 
					{
                        currentState = STATE_SEND;
                    }
					else
						currentState = STATE_IDLE;
                }
                break;
// -------------------------------------------------------------
// STATE: RECEIVE (Detect START condition and count pulses)
// -------------------------------------------------------------
            case STATE_RECEIVE:
                
				start_found=false;
				while (timeout < START_PULSE_TIMEOUT)
				{
					CLRWDT();
                    if (RX_PIN == 0) // RX line goes HIGH
					{
						start_found=true;
                        break;
                    }
                    __delay_ms(1);
                    timeout++;
				}
				if (start_found)
				{
					start_found = false;
// Wait for RX line to go LOW again
					while (timeout < START_PULSE_TIMEOUT)
					{
						CLRWDT();
                    	if (RX_PIN == 1) 
						{
                        	start_found = true;
// Prepare RX counter. Counting is handled in the ISR.
							rx_pulse_count=0;
                        	break;
                    	}
                    	__delay_ms(1);
                    	timeout++;
					}
				}
// When correct START condition is met, start counting pulses for a period of 300 ms
				if (start_found)
				{
					timeout = 0;
					while (timeout < COUNT_SAMPLE_TIME_WINDOW)
					{
						__delay_ms(1);
						timeout++;
					}
// Get reply from slave
					uint8_t reply=rx_pulse_count;
					CLRWDT();

					if ((reply>=1) && (reply<8))
					{
						current_antenna = reply;
						if ((current_antenna == selected_antenna) || (no_ant_req))
						{
// Show the currently switched antenna on the LED's
							DisplayAntennaSelection(current_antenna, 0);
							currentState = STATE_IDLE;
// After first enquiry, make selected antenna equal to current antenna
							if (no_ant_req)
								selected_antenna = current_antenna;
						}
						else
						{
							currentState = STATE_ERROR;
						}
					}
					else // reply >= 9 or out of range -> error
					{
// Switch OFF the antenna LED's
						DisplayAntennaSelection(0, 0);
// Switch ON the FAIL LED (red status)
						Set_Status_LED(COLOR_RED);
						currentState = STATE_ERROR;
					}
				}
				else
				{
// No ACK -> error
						DisplayAntennaSelection(0, 0);
						Set_Status_LED(COLOR_RED);
						currentState = STATE_ERROR;
				}
// Reset first cycle flag
				no_ant_req = false;
                break;
// -------------------------------------------------------------
// STATE: SEND (Send switch command) 
// -------------------------------------------------------------
            case STATE_SEND: 
				if ((selected_antenna >= 1) && (selected_antenna <= 7))
				{
                	if(Send_Frame(selected_antenna))
	                	currentState = STATE_RECEIVE;
					else
					{
						currentState = STATE_ERROR;
						DisplayAntennaSelection(0, 0);
                		Set_Status_LED(COLOR_RED);
					}
				}
                break;
// -------------------------------------------------------------
// STATE: ERROR 
// -------------------------------------------------------------
            case STATE_ERROR:
// Actual relay states are unknown
                current_antenna = 0; 
				DisplayAntennaSelection(0, 0);
                Set_Status_LED(COLOR_RED);
				CLRWDT();
// Wait for button press to reset error condition
                if ((BTN_UP == 0) || (BTN_DN == 0))
				{
                    __delay_ms(50);
                    while ((BTN_UP == 0) || (BTN_DN == 0))
						CLRWDT();
                    currentState = STATE_IDLE;
					Set_Status_LED(COLOR_OFF);
                }
                break;
        }
    }
}

/******************************************************************************/
/* bool Send_Frame(unit8_t data_mask)
** ----------------------------------
*/
bool Send_Frame(uint8_t pulses) 
{
	
// Make START condition on TX
    TX_PIN = 1;
    __delay_ms(START_PULSE_HIGH_TIME);
	CLRWDT();
// Check if slave has acknowledged; if not, return with error
	if (RX_PIN == 1)
	{
		TX_PIN = 0;
		return false;	// No ACK so return with an error
	}

    TX_PIN = 0;
    __delay_ms(START_PULSE_LOW_TIME);
// START condition has ended, ready to output pulses
	CLRWDT();

	for (uint8_t i = 0; i < pulses; i++)
	{
		TX_PIN = 1;
		__delay_ms(COUNTER_PULSE_HIGH_TIME);
		TX_PIN = 0;
		__delay_ms(COUNTER_PULSE_LOW_TIME);
	}
// TX line remains low, ready for next cycle. Return with "no error".
    return true;	
}

/******************************************************************************/
/* void Set_Status_LED(uint8_t color) 
** ----------------------------------
*/
void Set_Status_LED(uint8_t color) 
{
    switch (color) 
	{
        case COLOR_OFF:    
			LED_RED = 0; 
			LED_GREEN = 0; 
			break;
        case COLOR_GREEN:  
			LED_RED = 0; 
			LED_GREEN = 1; 
			break;
        case COLOR_RED:    
			LED_RED = 1; 
			LED_GREEN = 0; 
			break;
        case COLOR_ORANGE: 
			LED_RED = 1; 
			LED_GREEN = 1; 
			break;	
		default: 
			LED_RED = 1;
			LED_GREEN = 0;
			break;
    }
}
/******************************************************************************/
/* void DisplayAntennaSelection(uint8_t active, uint8_t selected)
** --------------------------------------------------------------
*/
void DisplayAntennaSelection(uint8_t active, uint8_t selected)
{
	uint8_t porta = 0;
	uint8_t portb = 0;

	if (currentState != STATE_ERROR)
		Set_Status_LED(COLOR_OFF);	
// Set the GREEN LED for the active antenna 
	switch (active)
	{
		case 3: porta = 0x20;
				break;
		case 2: porta = 0x08;
				break;
		case 1: porta = 0x02;
				break;
		case 6: portb = 0x20;
				break;
		case 5: portb = 0x08;
				break;
		case 4: portb = 0x02;
				break;
		case 7: Set_Status_LED(COLOR_GREEN);
				break;
	}
// Set GREEN + RED (= ORANGE) for selected antenna if required
	if (selected!=active)
	{
		switch (selected)
		{
			case 3: porta |= 0x30;
				break;
			case 2: porta |= 0x0C;
				break;
			case 1: porta |= 0x03;
				break;
			case 6: portb |= 0x30;
				break;
			case 5: portb |= 0x0C;
				break;
			case 4: portb |= 0x03;
				break;
			case 7: Set_Status_LED(COLOR_ORANGE);
				break;
		}
	}

	I2C_Write(MCP23017_ADDR, 0x12, porta); 
	__delay_ms(1);
    I2C_Write(MCP23017_ADDR, 0x13, portb); 
}

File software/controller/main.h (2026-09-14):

#ifndef MAIN_H
#define	MAIN_H

#include <xc.h>
#include <stdint.h>
#include <stdbool.h>
#include "interrupt.h"
#include "i2c.h"
#include "mcp23017.h"
#include "system.h"

// Configuration Bits (PIC16F1829)
#pragma config FOSC = INTOSC    // Internal oscillator
#pragma config WDTE = ON        // Watchdog Timer ON 
#pragma config PWRTE = ON       // Power-up Timer ON
#pragma config MCLRE = ON       // MCLR pin active
#pragma config CP = OFF         // Code Protection OFF
#pragma config BOREN = ON       // Brown-out Reset ON
#pragma config CLKOUTEN = OFF   // Clock Out function OFF
#pragma config IESO = OFF       // Internal/External Switchover OFF
#pragma config FCMEN = OFF      // Fail-Safe Clock Monitor OFF

#define _XTAL_FREQ 16000000     // 16 MHz; required for delay macros

// I/O pin definitions
#define BTN_UP      PORTCbits.RC0
#define BTN_DN      PORTCbits.RC1
#define LED_RED     PORTCbits.RC2
#define LED_GREEN   PORTCbits.RC3
#define RX_PIN      PORTBbits.RB7
#define TX_PIN      LATCbits.LATC7

// MCP23017 I2C Address, A0, A1, A2 tied to GND
#define MCP23017_ADDR 0x40

// State machine definitions
typedef enum {
    STATE_START,
	STATE_REQ_INFO,
    STATE_IDLE,
    STATE_SEND,
    STATE_RECEIVE,
    STATE_ERROR
} MasterState_t;

// Some timing stuff
#define START_PULSE_TIMEOUT		 ((uint16_t)1500)
#define COUNT_SAMPLE_TIME_WINDOW ((uint16_t)300)
#define START_PULSE_HIGH_TIME	 ((uint8_t)15)
#define START_PULSE_LOW_TIME	 ((uint8_t)5)
#define	COUNTER_PULSE_HIGH_TIME	 ((uint8_t)3)
#define	COUNTER_PULSE_LOW_TIME	 ((uint8_t)3)

// Globals
MasterState_t currentState = STATE_START;
uint8_t current_antenna = 0;   // 1..6 = antenna 1..6, 7 = all OFF, 0 = unknown
uint8_t selected_antenna = 1;  // Antenna selected by operator

void DisplayAntennaSelection(uint8_t active, uint8_t selected);
void Set_Status_LED(uint8_t color); // 0=OFF, 1=GREEN, 2=RED, 3=ORANGE
bool Send_Frame(uint8_t data_mask);

// LED color definitions
#define COLOR_OFF    0
#define COLOR_GREEN  1
#define COLOR_RED    2
#define COLOR_ORANGE 3

#endif
